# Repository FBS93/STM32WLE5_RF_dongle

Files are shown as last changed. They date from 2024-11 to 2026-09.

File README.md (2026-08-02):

# SMT32WLE5_RF_dongle

This project is developed using [Embedded Workbench](doc/ew.md).

The **SMT32WLE5_RF_dongle** is a compact RF dongle designed for wireless communication via USB. Built around the STM32WLE5C8U6 microcontroller, it enables straightforward radio communication in the sub-GHz range of 150–960 MHz. Supports LoRa and (G)FSK modulations for both transmission and reception, as well as BPSK/(G)MSK for transmission only.

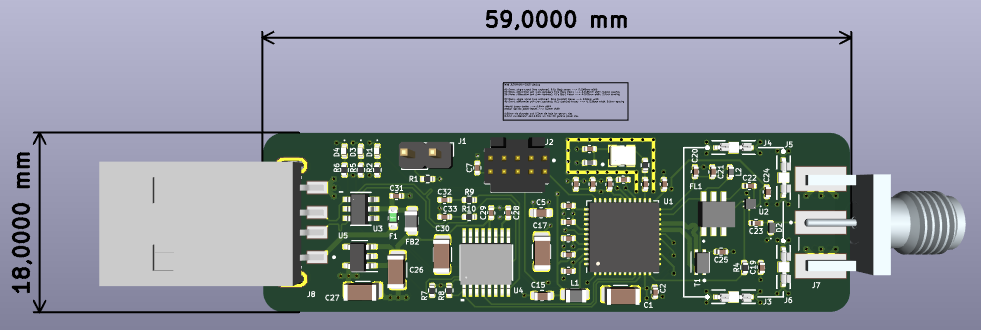
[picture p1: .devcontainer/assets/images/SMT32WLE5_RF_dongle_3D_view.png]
SMT32WLE5_RF_dongle


This repository provides both the hardware design and an example software project that includes firmware for the STM32WLE5C8U6 microcontroller, along with a Kivy-based desktop app to control the RF dongle. The project is packaged in a devcontainer for Visual Studio Code, but adaptable as needed.

Below you will find a brief guide on how to set up the development environment used.

# Setting up the development environment

## Development environment

The following setup was used during the development of this project. While the project should work with similar setups, using these versions will help minimize compatibility issues.

- **Windows Subsystem for Linux (WSL)**: version 2.3.24.0
- **Visual Studio Code**: version 1.95.2
- **Remote Development (VSode extension)**:  version 0.26.0
- **ST-LINK/V2**

Useful links:

- [Developing inside a Container](https://code.visualstudio.com/docs/devcontainers/containers)
- [Connecting USB devices to WSL](https://learn.microsoft.com/en-us/windows/wsl/connect-usb)

## Quick start

Once inside the devcontainer you will find the following folders:

- `hw/`: contains all the hardware design files of this project. You can find the full hardware design in a KiCad project format, including the schematic, PCB layout, and associated files. Additionally, the folder includes the KiCad libraries that were used for this design.

- `software/stm32wle5_rf_dongle_example/`: contains an example firmware for the STM32WLE5C8U6 microcontroller, along with a Kivy-based desktop app to control the RF dongle.

After opening the VSCode workspace defined in the `.vscode/.code-workspace` file, you should see the following icons in the VSCode status bar: VSCode status bar

- **[Preset]**: Presets for the STM32WLE5C8U6 firmware

- **🛠 C**: Predefined tasks to work with the STM32WLE5C8U6 firmware
  - 🔨 Build &rarr; Compile the firmware
  - 🐞 Debug &rarr; Debug the firmware on target
  - ⚡ Flash &rarr; Flash the firmware to the target
  - 🧹 Clean &rarr; Remove firmware build

- **🐍 Python**:  Predefined tasks to work with the Kivy desktop app
  - ▶ Run &rarr; Execute the Kivy app
  - 🐞 Debug &rarr; Debug the Kivy app
  - 🧹 Clean &rarr; Clean all \_\_pycache__

- **🧰 Toolbox**: Predefined tasks to open the tools used for the Hardware and Software design
  - ⚙️ STM32CubeMX
  - ⚡ KiCad

## Running the example software

The following screenshots show the communication between two SMT32WLE5_RF_dongle using the example software provided in this repository.

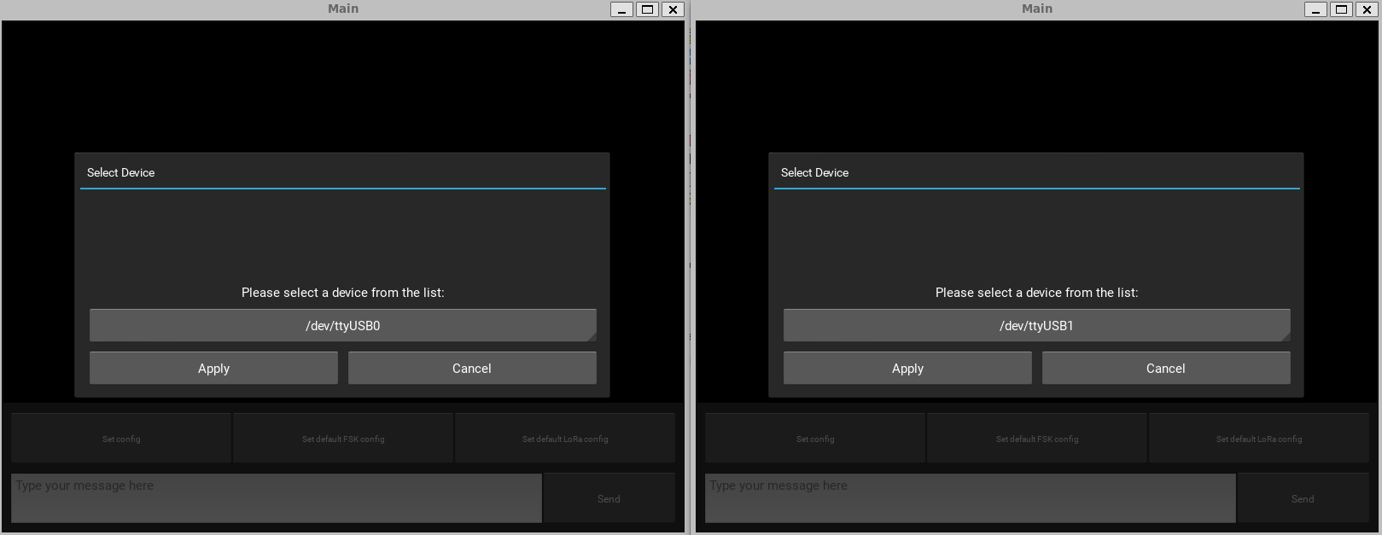
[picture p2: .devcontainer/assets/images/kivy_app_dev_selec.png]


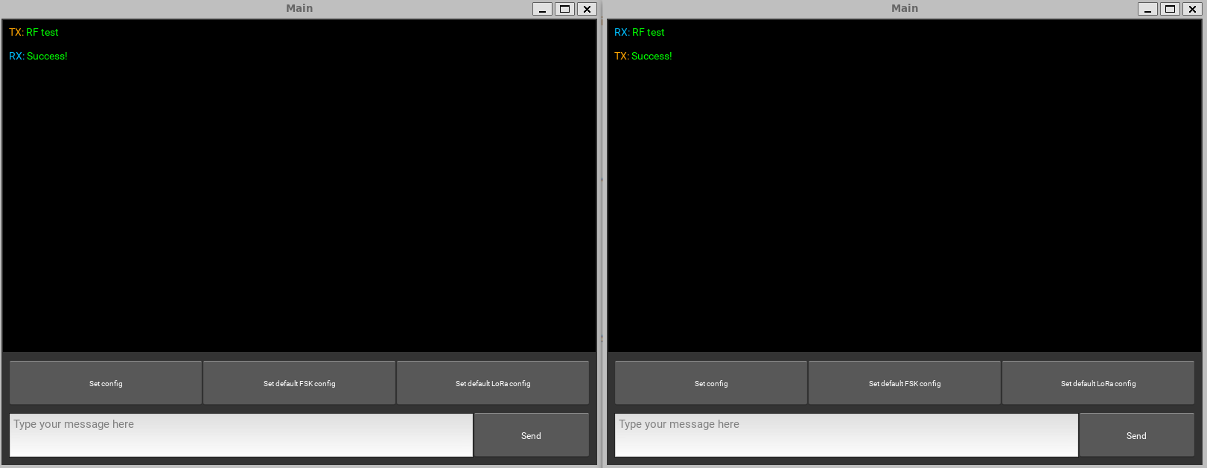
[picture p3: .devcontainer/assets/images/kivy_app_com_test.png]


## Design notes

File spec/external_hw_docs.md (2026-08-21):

# EHW_DOC_1

STMicroelectronics RM0461, reference manual for STM32WLEx advanced Arm®-based 32-bit MCUs with sub-GHz radio solution.

## References

- RM0461: STM32WLEx advanced Arm®-based 32-bit MCUs with sub-GHz radio solution - Reference manual
  - AI processing source: [rm0461-stm32wle5xx-advanced-armbased-32bit-mcus-stmicroelectronics.md](stakeholder_spec_parsed/external_doc/rm0461-stm32wle5xx-advanced-armbased-32bit-mcus-stmicroelectronics.md)
  - Original source: [rm0461-stm32wle5xx-advanced-armbased-32bit-mcus-stmicroelectronics.pdf](stakeholder_spec/external_doc/rm0461-stm32wle5xx-advanced-armbased-32bit-mcus-stmicroelectronics.pdf)

# EHW_DOC_2

STMicroelectronics DS13105, datasheet for STM32WLE5xx and STM32WLE4xx multiprotocol LPWAN 32-bit Arm® Cortex®-M4 MCUs.

## References

- DS13105: STM32WLE5xx STM32WLE4xx - Multiprotocol LPWAN 32-bit Arm® Cortex®-M4 MCUs
  - AI processing source: [stm32wle5jc.md](stakeholder_spec_parsed/external_doc/stm32wle5jc.md)
  - Original source: [stm32wle5jc.pdf](stakeholder_spec/external_doc/stm32wle5jc.pdf)

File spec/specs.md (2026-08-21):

# SPEC_1

The product shall be a laboratory RF dongle based on the selected STM32WLE5 microcontroller (MCU) named `STM32WLE5_RF_dongle`.

Milestone: M_1

Status: approved

# SPEC_2

The `STM32WLE5_RF_dongle` hardware and software shall both be developed within this project.

Milestone: M_1

Status: approved

# SPEC_3

The `STM32WLE5_RF_dongle` shall be operated from a USB-connected host and support both manual control and automated scripting.

Milestone: M_1

Status: approved

# SPEC_4

The host shall be able to configure RF operation of `STM32WLE5_RF_dongle` using all modulation and configuration capabilities provided by the selected STM32WLE5 MCU.

Milestone: M_1

Status: approved

# SPEC_5

The host shall be able to request RF transmission and reception to `STM32WLE5_RF_dongle`.

Milestone: M_1

Status: approved

# SPEC_6

The `STM32WLE5_RF_dongle` shall provide the host with the active RF operation and radio operational errors.

Milestone: M_1

Status: approved

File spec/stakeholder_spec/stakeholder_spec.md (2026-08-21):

# Stakeholder specification

## Product purpose

The product shall be a laboratory RF dongle based on the selected STM32WLE5 microcontroller (MCU) named `STM32WLE5_RF_dongle`. The `STM32WLE5_RF_dongle` hardware and software shall both be developed within this project.

## Host control and RF operation

The `STM32WLE5_RF_dongle` shall be operated from a USB-connected host and support both manual control and automated scripting.

The host shall be able to configure RF operation of `STM32WLE5_RF_dongle` using all modulation and configuration capabilities provided by the selected STM32WLE5 MCU.

The host shall be able to request RF transmission and reception to `STM32WLE5_RF_dongle`.

## Operational status and diagnostics

The `STM32WLE5_RF_dongle` shall provide the host with the active RF operation and radio operational errors.

## External documentation

- [RM0461: STM32WLEx advanced Arm®-based 32-bit MCUs with sub-GHz radio solution - Reference manual](external_doc/rm0461-stm32wle5xx-advanced-armbased-32bit-mcus-stmicroelectronics.pdf)
- [DS13105: STM32WLE5xx STM32WLE4xx - Multiprotocol LPWAN 32-bit Arm® Cortex®-M4 MCUs](external_doc/stm32wle5jc.pdf)

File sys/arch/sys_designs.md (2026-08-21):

# sys_designs

## SYS_ARCH_DESIGN_1

Name: sysd_systemModes

The system modes are defined in the [sys_modes_state_diagram.md](sys_modes_state_diagram.md) document.

Upstream traceability:
- [SYS_REQ_PRODUCT_1](../req/sys_product.md#sys_req_product_1)
- [SYS_REQ_INTERFACE_1 — command processing](../req/sys_interfaces.md#command-processing)
- [SYS_REQ_INTERFACE_1 — host requests](../req/sys_interfaces.md#host-to-target-requests)
- [SYS_REQ_INTERFACE_2](../req/sys_interfaces.md#sys_req_interface_2)
- [RX operation](../req/sys_interfaces.md#rx-operation)
- [CAD operation](../req/sys_interfaces.md#cad-operation)
- [SYS_REQ_PARAMETER_46](../req/sys_parameters.md#sys_req_parameter_46)

Status: approved

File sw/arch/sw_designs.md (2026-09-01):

# sw_designs

## SW_ARCH_DESIGN_1

Name: swd_eventDrivenModel

This architecture shall follow an event-driven model using Event Driven Framework (EDF).

Events:
- `GET_CONFIG_REQUEST`
  - Description: Represents the [GET_CONFIG_REQUEST](../../sys/req/sys_interfaces.md#get-config-request) command.
- `SET_CONFIG`
  - Description: Represents the [SET_CONFIG](../../sys/req/sys_interfaces.md#set-config-request) command.
  - Parameters:
    - `configuration_payload`: [Configuration Payload](../../sys/req/sys_interfaces.md#configuration-payload).
- `CALIBRATE`
  - Description: Represents the [CALIBRATE](../../sys/req/sys_interfaces.md#calibrate-request) command.
  - Parameters:
    - `calibration_payload`: [Calibration Payload](../../sys/req/sys_interfaces.md#calibration-payload).
- `TX_PACKET`
  - Description: Represents the [TX_PACKET](../../sys/req/sys_interfaces.md#tx-packet-request) command.
  - Parameters:
    - `tx_packet_payload`: [TX Packet Payload](../../sys/req/sys_interfaces.md#tx-packet-payload).
- `RX_START`
  - Description: Represents the [RX_START](../../sys/req/sys_interfaces.md#rx-start-request) command.
- `CAD_START`
  - Description: Represents the [CAD_START](../../sys/req/sys_interfaces.md#cad-start-request) command.
- `TX_CONTINUOUS_WAVE`
  - Description: Represents the [TX_CONTINUOUS_WAVE](../../sys/req/sys_interfaces.md#tx-continuous-wave-request) command.
- `TX_CONTINUOUS_PREAMBLE`
  - Description: Represents the [TX_CONTINUOUS_PREAMBLE](../../sys/req/sys_interfaces.md#tx-continuous-preamble-request) command.
- `STOP`
  - Description: Represents the [STOP](../../sys/req/sys_interfaces.md#stop-request) command.
- `GET_DIAGNOSTICS_REQUEST`
  - Description: Represents the [GET_DIAGNOSTICS_REQUEST](../../sys/req/sys_interfaces.md#get-diagnostics-request) command.
- `GET_CONFIG_RESPONSE`
  - Description: Represents the [GET_CONFIG_RESPONSE](../../sys/req/sys_interfaces.md#get-config-response) command.
  - Parameters:
    - `configuration_payload`: [Configuration Payload](../../sys/req/sys_interfaces.md#configuration-payload).
- `GET_DIAGNOSTICS_RESPONSE`
  - Description: Represents the [GET_DIAGNOSTICS_RESPONSE](../../sys/req/sys_interfaces.md#get-diagnostics-response) command.
  - Parameters:
    - `diagnostics_payload`: [Diagnostics Payload](../../sys/req/sys_interfaces.md#diagnostics-payload).
- `RX_PACKET`
  - Description: Represents the [RX_PACKET](../../sys/req/sys_interfaces.md#rx-packet) command.
  - Parameters:
    - `rx_packet_payload`: [RX Packet Payload](../../sys/req/sys_interfaces.md#rx-packet-payload).
- `CAD_DETECTED`
  - Description: Represents the [CAD_DETECTED](../../sys/req/sys_interfaces.md#cad-detected) command.
- `OPERATION_COMPLETE`
  - Description: Indicates that the active RF operation has completed.
- `HOST_DATA_AVAILABLE`
  - Description: Indicates that data received from the host is available for processing.

Upstream traceability:
- [SW_REQ_CLI_1](../req/sw_cli.md#sw_req_cli_1)
- [SW_REQ_CONTROLLER_1](../req/sw_controller.md#sw_req_controller_1)
- [SW_REQ_INTERFACE_1](../req/sw_interfaces.md#sw_req_interface_1)
- [SW_REQ_INTERFACE_2](../req/sw_interfaces.md#sw_req_interface_2)

Status: approved

## SW_ARCH_DESIGN_2

Name: swd_platform

The platform shall be defined as follows:

Toolchains:
- Host SiL/emulation: use the existing [linux_gcc.cmake](../../tools/cmake/toolchains/linux_gcc.cmake) toolchain.
- Target executable: use the existing [arm_gcc.cmake](../../tools/cmake/toolchains/arm_gcc.cmake) toolchain.

Build configuration:
- The following elements are CMake configure presets. Each preset selects the build configuration, optimization level and debug information level. The common warning options `-Wall -Wextra -Wconversion -Werror` apply to the listed product presets through a base configuration.
  - Host SiL/emulation:
    - `host`: CMAKE_BUILD_TYPE `Release`, optimization `-O2` and debug information `-g2`.
    - `host_debug`: CMAKE_BUILD_TYPE `Debug`, optimization `-O0` and debug information `-g3`.
    - `host_hard_debug`: CMAKE_BUILD_TYPE `Debug`, optimization `-O0`, debug information `-g3` and generation of preprocessed files for inspection `-save-temps=obj -P`.
  - Target:
    - `target_stm32wle5c8u6`: CMAKE_BUILD_TYPE `Release`, optimization `-O2` and debug information `-g2`.
    - `target_stm32wle5c8u6_debug`: CMAKE_BUILD_TYPE `Debug`, optimization `-O0` and debug information `-g3`.
    - `target_stm32wle5c8u6_hard_debug`: CMAKE_BUILD_TYPE `Debug`, optimization `-O0`, debug information `-g3` and generation of preprocessed files for inspection `-save-temps=obj -P`.

RAM layout:
| Name | Description | Start address | End address |
|---|---|---|---|
| target_sram2 | STM32WLE5C8U6 SRAM2. The C8 density provides 20 Kbytes; RM0461 maps SRAM2 from 0x2000 8000. | 0x2000 8000 | 0x2000 CFFF |

ROM layout:
| Name | Description | Start address | End address |
|---|---|---|---|
| target_program_flash | STM32WLE5C8U6 user flash. The C8 density provides 64 Kbytes and RM0461 maps user flash from 0x0800 0000. | 0x0800 0000 | 0x0800 FFFF |

NVM layout:
| Name | Description | Start address | End address |
|---|---|---|---|
| target_nvm_none | No NVM region is currently used. | N/A | N/A |

Debug configuration:
- The target shall use SWD as its debug interface.

Embedded C Framework (ECF) integration:
- The target ECF stdout shall use the ITM/TPIU/SWO interface with the following configuration:
  - TPIU asynchronous output protocol: NRZ.
  - Nominal SWO bitrate: 2 Mbit/s.
  - The target ECF stdout shall use a non-blocking 1024-byte buffer.
- Target ECF stdin is not supported.

Upstream traceability:
- [SW_REQ_PLATFORM_1](../req/sw_platform.md#sw_req_platform_1)
- [SW_REQ_PLATFORM_2](../req/sw_platform.md#sw_req_platform_2)
- [SW_REQ_PLATFORM_3](../req/sw_platform.md#sw_req_platform_3)
- [SW_REQ_PLATFORM_4](../req/sw_platform.md#sw_req_platform_4)
- [SW_REQ_PLATFORM_5](../req/sw_platform.md#sw_req_platform_5)
- [SW_REQ_PLATFORM_6](../req/sw_platform.md#sw_req_platform_6)
- [SW_REQ_PLATFORM_7](../req/sw_platform.md#sw_req_platform_7)

Status: approved

## SW_ARCH_DESIGN_3

Name: swd_hostCliScope

The [swc_hostCli](sw_components.md#sw_arch_component_1) shall be implemented as a Python 3 application for POSIX. It is defined up to software architecture only; downstream software-domain processes do not apply. The [swc_hostCli](sw_components.md#sw_arch_component_1) remains subject to system integration and qualification testing.

Upstream traceability:
- [SW_REQ_CLI_1](../req/sw_cli.md#sw_req_cli_1)

Status: approved

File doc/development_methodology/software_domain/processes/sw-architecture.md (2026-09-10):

# sw-architecture

## Purpose

Define software architecture from software requirements.

## Input work products

- Software requirements

## Output work products

- Software architecture

## Steps

1. Review the software requirements.
2. Identify the software architecture elements required to address the software requirements.
3. Define the software architecture based on the identified software architecture elements.
4. Define traceability between software architecture elements and software requirements.
5. Check the software architecture for completeness, consistency and correctness.

## Guidelines

### Software architecture work product

The software architecture work product shall follow the [Architecture definition](../../resources/architecture_definition.md).

#### Architecture model

The software architecture shall follow an event-driven model. The use of this architecture model with the [Event Driven Framework (EDF)](../../../../sw/ecf/event_driven_framework/doc/edf.md) shall be defined as a software design.

The software architecture shall be aligned with the capabilities and features of the [Event Driven Framework (EDF)](../../../../sw/ecf/event_driven_framework/doc/edf.md).

The software design defining the use of the event-driven architecture model shall contain:
- A justification of the selection of the event-driven model and the use of EDF with a fixed sentence.
- Architectural decisions specific to the use of the event-driven model, such as active-object priorities (including preemption-threshold relationships when applicable), event-pool sizing, time-event usage, and other applicable model-specific decisions.
- The definition of the complete set of available software events. Each event shall be specified with:
  - An event name in UPPER_SNAKE_CASE. The event name shall be unique, as it is used as the event identifier.
  - A description defining the event. The description shall include all necessary information to fully specify the event, written in a clear and concise manner.
  - Event parameters when applicable. Each parameter shall be specified with:
    - A parameter name in lower_snake_case. The parameter name shall be unique within the event, as it is used as the parameter identifier.
    - A description defining the parameter. The description shall include all necessary information to fully specify the parameter, written in a clear and concise manner.

The following template shall be used for the description of this software design:

```md
This architecture shall follow an event-driven model using Event Driven Framework (EDF).
<Event-driven model architectural decisions>.

Events:
- `<EVENT_NAME>`
  - Description: <Event description>.
  - Parameters:
    - `<param_name>`: <Parameter description>.
```

The `Parameters` subsection shall be included only when the event has parameters.

In this architecture model, all project-specific software components shall be defined as active objects. Each active object shall:
- Encapsulate its own state and behavior.
- Process events asynchronously without blocking or sharing resources with other software components.

Hint: If a shared resource is identified, the solution might be to isolate it in a dedicated active object and access it from other active objects through events.

Events, using the EDF publish/subscribe mechanism, shall be the only way of interaction between software components. Direct function calls between software components are not permitted.

A software component named `EDF` shall be defined and linked to the software design defining the use of the event-driven architecture model. This software component shall be used in the architecture views to represent the unique way of interaction between project-specific software components.

Each software component shall use a single architecture interface to `EDF` software component. The description of this interface shall contain:
- A list of published events.
- A list of subscribed events.

Events in both lists shall be referenced only by their `EVENT_NAME`, which is the unique identifier of the event defined in the software design defining the use of the event-driven architecture model.

The following template shall be used for the description of each interface used for a given software component:

```md
Published events:
- <EVENT_NAME>
- <EVENT_NAME>

Subscribed events:
- <EVENT_NAME>
- <EVENT_NAME>
```

#### Platform

The software architecture shall define the platform as a software design.

The platform software design shall define the platform-specific architectural decisions and default configurations.

All platform characteristics required to define the software architecture shall be provided by upstream elements. If relevant platform characteristics are not defined by upstream elements and no valid default option is available, the software architecture process shall not be completed until the missing information is defined upstream.

The platform software design shall contain:
- Toolchains:
  - If the target toolchain is not explicitly defined by upstream elements and the MCU architecture is ARM, the default option for the target shall be the [arm_gcc.cmake](../../../../tools/cmake/toolchains/arm_gcc.cmake) toolchain.
  - If the host toolchain is not explicitly defined by upstream elements, the default option for the host shall be the [linux.cmake](../../../../tools/cmake/toolchains/linux_gcc.cmake) toolchain.
- Build configuration:
  - If upstream elements do not specify the build configuration and the MCU architecture is ARM, the default build presets shall be:
    - `host`: Host execution (SiL) in release configuration.
    - `host_debug`: Host execution (SiL) in debug configuration.
    - `host_hard_debug`: Host execution (SiL) in debug configuration with preprocessed source code available for inspection.
    - `target_<platform>`: Target embedded execution in release configuration.
    - `target_<platform>_debug`: Target embedded execution in debug configuration.
    - `target_<platform>_hard_debug`: Target embedded execution in debug configuration with preprocessed source code available for inspection.
  - If build flags for the selected toolchain are not explicitly defined or are not self-evident, they shall be defined here, including the presets to which they apply.
- ISR integration strategy:
  - Architectural decisions for ISR integration, including interrupt sources, ownership, priority ordering and other applicable ISR-specific decisions.
- Memory layout:
  - A memory layout divided into RAM layout, ROM layout (e.g., program flash, ...) and NVM layout (e.g., persistent parameters, persistent data, ...). Each memory layout shall be represented as a Markdown table. Each row of this table represents a memory region of the memory layout and may describe any level of granularity, ranging from a memory block to individual parameters. Each memory region shall be specified with:
    - A memory region name in lower_snake_case. The memory region name shall be unique across all memory layouts, as it is used as the memory region identifier.
    - A description defining the memory region. The description shall include all necessary information to fully specify the memory region, written in a clear and concise manner.
    - The start address of the memory region.
    - The end address of the memory region.
- Debug configuration:
  - Definition of the debug interfaces used (e.g., SWD, JTAG, etc.).
- [Embedded C Framework (ECF)](../../../../sw/ecf/doc/ecf.md) integration:
  - Integration strategy for [Embedded Base Framework (EBF)](../../../../sw/ecf/embedded_base_framework/doc/ebf.md) stdin/stdout integration. Upstream elements shall define the interface used for this integration. If no further detail is specified by upstream elements, the default shall be:
    - Stdin listener shall be executed in the reception ISR context.
    - Stdout shall use buffered transmission handled by ISR.
    - Stdout buffer size shall be configurable and defined according to the memory constraints of the target platform.

The following template shall be used for the description of this software design:

```md
The platform shall be defined as follows:

Toolchains:
- <Design decisions related to the selected toolchains>.

Build configuration:
- <Design decisions related to the selected build configuration>.

ISR integration strategy:
- <Design decisions related to the ISR integration strategy>.

RAM layout:
| Name | Description | Start address | End address |
|---|---|---|---|
| <memory_region_name> | <Description>. | <Start address in hexadecimal format> | <End address in hexadecimal format> |

ROM layout:
| Name | Description | Start address | End address |
|---|---|---|---|
| <memory_region_name> | <Description>. | <Start address in hexadecimal format> | <End address in hexadecimal format> |

NVM layout:
| Name | Description | Start address | End address |
|---|---|---|---|
| <memory_region_name> | <Description>. | <Start address in hexadecimal format> | <End address in hexadecimal format> |

Debug configuration:
- <Design decisions related to the selected debug configuration>.

Embedded C Framework (ECF) integration:
- <Design decisions related to the Embedded C Framework (ECF) integration strategy>.
```

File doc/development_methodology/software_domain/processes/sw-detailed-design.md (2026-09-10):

# sw-detailed-design

## Purpose

Define software detailed design from software requirements and software architecture.

## Input work products

- Software requirements
- Software architecture

## Output work products

- Software detailed design

## Steps

1. Review the software requirements and software architecture.
2. Identify the software units required to address the software requirements and software architecture.
3. Define the detailed design of each software unit.
4. Define traceability between software detailed design and software architecture.
5. Check the software detailed design for completeness, consistency and correctness.

## Guidelines

### Software detailed design work product

Software detailed designs shall be derived from software architecture and software requirements.

Software requirements shall be used only as complementary input when the software architecture does not fully define the required behavior.

Software detailed designs shall not define direct traceability to software requirements.

All software architecture elements shall be traced to one or more software units. Each software architecture element may be refined into one or more software units (1:1 or 1:N) depending on the software detailed design needs.

In cases where a software component is refined into multiple software units (1:N), it is recommended to group the corresponding software units under a common folder named the same as the software component.

Each software unit shall use a descriptive `lower_snake_case` name. This name shall be the common base name for its folder, Markdown document, headers, source files and implemented library. When a software component is refined 1:1 as a software unit, the software unit name shall be derived by removing the architectural `swc_` prefix and converting the remaining name to `lower_snake_case`.

Software units shall be reused from existing libraries when available. Before creating a new software unit or implementing project-specific functionality within a software unit, it shall be verified whether the required functionality can be provided by [Embedded C Framework (ECF)](../../../../sw/ecf/doc/ecf.md). If a specific implementation within a software unit is still required, it shall be assessed whether it can be fully or partially designed as reusable software for other projects and therefore implemented in [Embedded C Framework (ECF)](../../../../sw/ecf/doc/ecf.md). Project-specific software implementation shall be minimized.

Each project-specific software unit shall have its own software detailed design and shall consist of:
- A Markdown document named `<sw_unit_name>.md` following the template defined in [embedded_c_guidelines.md](../resources/embedded_c_coding_guidelines.md#librarymodule-documentation) with the following additional information:
  - A unique identifier defined as a top Markdown heading (all other headings defined in the [embedded_c_guidelines.md](../resources/embedded_c_coding_guidelines.md#librarymodule-documentation) template shall be shifted one level below this top heading), following the pattern: `SW_DETAILED_DESIGN_<X>`
    - `<X>` is a monotonically increasing number that shall never be reused.
  - The `<Library/module name> overview` chapter placeholder shall be replaced with the software unit name used in the document name using the following pattern `<Software unit name> overview`. The chapter shall contain the following information:
    - A description defining the software unit. The description shall include all necessary information to fully specify the software unit, written in a clear and concise manner.
      - The description of software units with executable behavior shall document that all fault handling not explicitly defined by upstream elements shall be handled using a Design by Contract (DbC) approach with the [Embedded Assert Framework (EAF)](../../../../sw/ecf/embedded_assert_framework/doc/eaf.md).
    - Upstream traceability to one or more software architecture elements. Shall be defined as a list of Markdown links referencing the corresponding software architecture elements.
    - A list of hardware resources used directly by the software unit, including their usage.
    - A list of external library dependencies, including their usage.
  - A status indicating the approval state of the software unit detailed design. Shall use exactly one of these values: `not approved`, `approved`.
  - The remaining chapters of the [library/module documentation](../resources/embedded_c_coding_guidelines.md#librarymodule-documentation) template shall follow this project-specific content in their original order.
- A behavioral model, when required. Each software unit that requires behavioral modeling shall have exactly one representation, selected as follows:
  - Mermaid shall be used for manual design, review and implementation. Mermaid models shall be `.md` files containing `mermaid` blocks and may define HSMs using `stateDiagram-v2` and activities using `flowchart`, as needed.
  - [MBSE](https://github.com/FBS93/mbse) shall be used when model execution, automated semantic validation or generation is required.
- Header files of the software unit, if any. When a public interface is required, `<sw_unit_name>.h` shall define it. Additional header files, if any, shall be named following the pattern `<sw_unit_name>_<header_specific_suffix>.h` and are intended to support the internal structure and detailed design of the software unit. All header files of the software unit shall follow the rules defined in [embedded_c_guidelines.md](../resources/embedded_c_coding_guidelines.md).

The following additions to the Markdown document template shall be applied to project-specific software units, in addition to the template defined in [embedded_c_guidelines.md](../resources/embedded_c_coding_guidelines.md#librarymodule-documentation):

```md
# SW_DETAILED_DESIGN_<X>

## <Software unit name> overview

<Description>.

Upstream traceability:
- [<UPSTREAM_ELEMENT_UNIQUE_ID>](#...)

Hardware resources:
- <Hardware resource>: <Short description of its usage>

External dependencies:
- <External library name>: <Short description of its usage>

Status: <status>

<Remaining chapters from the [library/module documentation](../resources/embedded_c_coding_guidelines.md#librarymodule-documentation) template, in their original order.>
```

For software units with executable behavior, the following text shall be inserted immediately after `<Description>.`:

```md
All undefined fault handling cases shall be handled using a Design by Contract (DbC) approach with the Embedded Assert Framework (EAF) as follows:
  - An assert shall be triggered for any unexpected software condition (e.g., invalid states, unexpected values, unexpected execution paths, invalid function parameters, ...).
  - Upon assert trigger, the software shall enter an infinite loop with a critical section active to prevent further execution.
```

For software units with executable behavior, the following dependency shall also be included under `External dependencies`:

```md
- Embedded Assert Framework (EAF): Provides assertions to enforce Design by Contract (DbC) in all undefined fault handling cases.
```

#### Active object detailed design

If the software architecture specifies an event-driven model as a software design, all software components defined in the architecture as active objects shall be refined 1:1 into software units. A dedicated software unit named `events` shall be defined as header-only, containing all events defined in this software design, so that it is available to all active objects and can be used during implementation. This does not preclude the definition of other types of software units derived from other software architecture elements.

The software detailed design of software units implemented as active objects shall not duplicate information already defined in the corresponding software component. Instead, it shall extend it where needed and define upstream traceability to the corresponding software component.

The software detailed design of software units implemented as active objects shall be aligned with the capabilities and features of the [Event Driven Framework (EDF)](../../../../sw/ecf/event_driven_framework/doc/edf.md). As this framework will be used for their implementation, it shall be listed as a dependency in the software detailed design.

The software detailed design of a software unit implemented as an active object shall contain the following information in addition to the generic software unit detailed design:
- The definition of its Hierarchical State Machine (HSM) and activities in its behavioral model.
  - The HSM definition shall be kept as simple as possible. It shall only extract event parameters and apply minimal logic to trigger specific functions (activities) based on the received event. Functional logic shall not be implemented directly in the HSM.
  - All activities and states defined in the HSM shall correspond to function names to be implemented. These function names shall follow the naming conventions defined in [embedded_c_guidelines.md](../resources/embedded_c_coding_guidelines.md#naming-conventions).
  - Activities defined in the HSM shall be declared in a header file named `<sw_unit_name>_activities.h` to allow unit testing when required.

#### Platform package detailed design

If the software architecture specifies the platform as a software design, a software unit of type platform package shall be defined. Existing platform packages in [Embedded C Framework (ECF)](../../../../sw/ecf/doc/ecf.md) shall be reviewed first and reused when available. A new platform package may be project-specific at `sw/src/<platform_name>_platform/`; when it shows actual reuse potential, it may be promoted to `sw/ecf/platform/<platform_name>/`. Only one canonical active implementation shall be used, so promotion shall replace the project-specific implementation rather than copy it.

A project-specific platform package shall use the project-specific software unit template defined above. A reusable ECF platform package shall use only the [library/module documentation](../resources/embedded_c_coding_guidelines.md#librarymodule-documentation) template and shall not contain project-specific traceability.

A software unit named `stdio` shall be defined within the platform package to implement [Embedded Base Framework (EBF)](../../../../sw/ecf/embedded_base_framework/doc/ebf.md) stdin/stdout integration as specified in the platform software design. Whether within a project-specific or ECF platform package, its documentation shall use only the template defined in [embedded_c_guidelines.md](../resources/embedded_c_coding_guidelines.md#librarymodule-documentation).

For a reused or promoted ECF platform package, the project shall retain a software detailed design Markdown document based on the project-specific software unit template defined above. Only its `<Description>` placeholder shall be specialized, using exactly the following text:

```md
This software unit is implemented by the [<platform_name> ECF platform package](<link_to_ECF_platform_package_markdown_document>).
```

A platform package shall be identified by `<platform_name>`, which shall be a descriptive identifier reflecting its scope (e.g., MCU family, board, execution environment, ...). In ECF platform packages, `ECF_TARGET_PLATFORM` name shall equal the ECF platform package folder name `<platform_name>`.

The [STM32F103C8Tx platform package](../../../../sw/ecf/platform/stm32f103c8tx/doc/stm32f103c8tx_platform_package.md) shall be used as the reference example for platform packages.

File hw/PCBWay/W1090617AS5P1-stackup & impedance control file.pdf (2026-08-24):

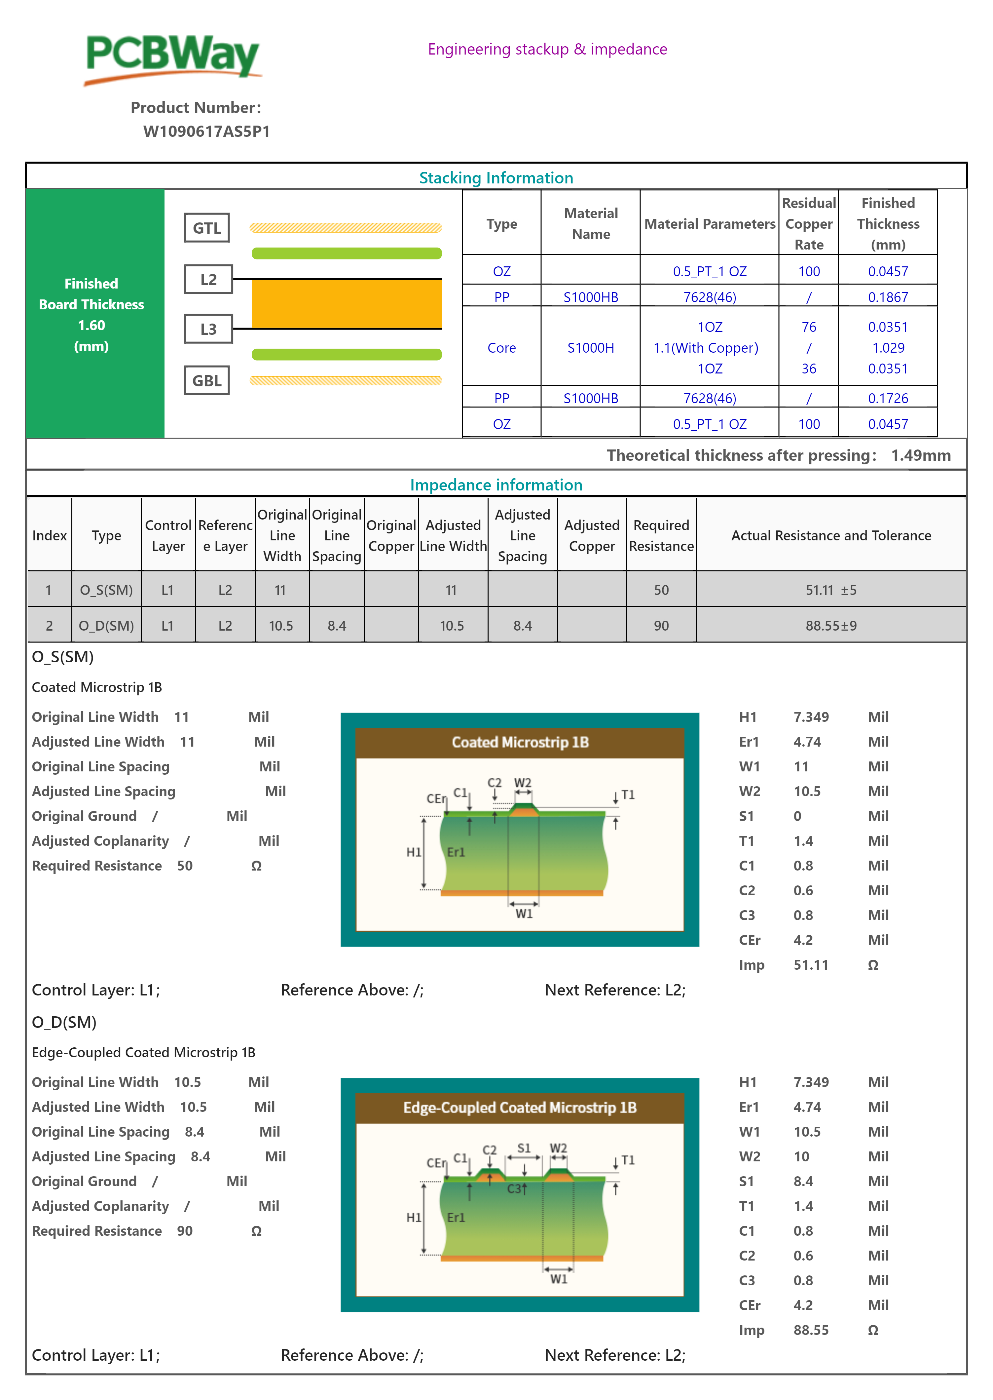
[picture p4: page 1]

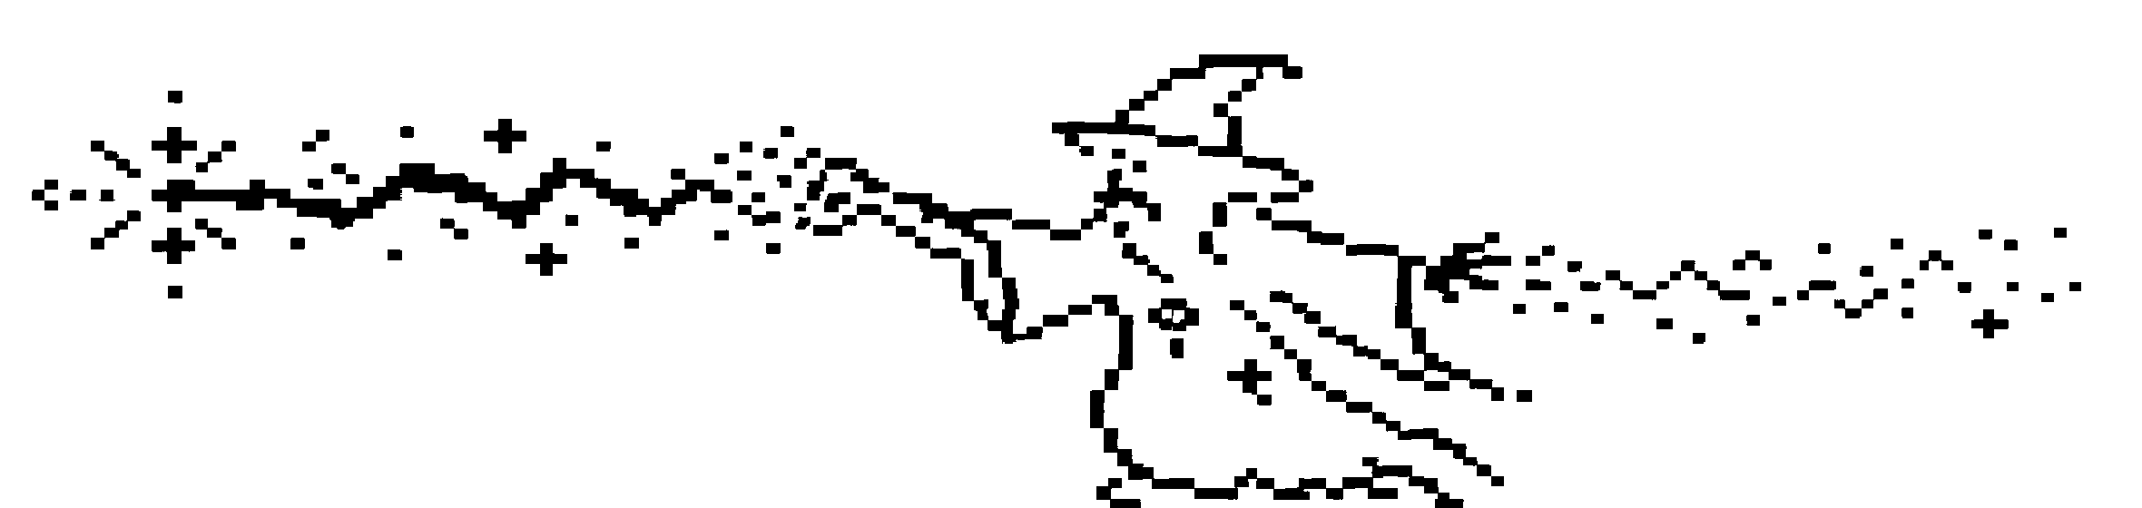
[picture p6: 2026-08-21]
hw/KiCad/assets/RF_Wizard.png

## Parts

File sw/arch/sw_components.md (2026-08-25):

# sw_components

## SW_ARCH_COMPONENT_1

Name: swc_hostCli

Host-side software component. It accepts the user command line and maps the CLI behavior to the target protocol requests and responses.

The component uses [`swi_hostUsbControl`](sw_interfaces.md#sw_arch_interface_1), as the logical host-control boundary to the target deployment.

Upstream traceability:
- [SW_REQ_CLI_1](../req/sw_cli.md#sw_req_cli_1)

References:
- [SW_ARCH_INTERFACE_1](sw_interfaces.md#sw_arch_interface_1)

Status: approved

## SW_ARCH_COMPONENT_2

Name: swc_hostCommandManager

Target-side active object responsible for the host-control boundary. It owns and realizes [`swi_hostUsbControl`](sw_interfaces.md#sw_arch_interface_1) and uses [`swi_hostCommandManagerEdf`](sw_interfaces.md#sw_arch_interface_4) as its single EDF architecture interface: it publishes accepted host-control requests and subscribes to target result events, exposing back those results through [`swi_hostUsbControl`](sw_interfaces.md#sw_arch_interface_1).

Upstream traceability:
- [SW_REQ_CONTROLLER_1](../req/sw_controller.md#sw_req_controller_1)
- [SW_REQ_INTERFACE_1](../req/sw_interfaces.md#sw_req_interface_1)
- [SW_REQ_PLATFORM_4](../req/sw_platform.md#sw_req_platform_4)

References:
- [SW_ARCH_INTERFACE_1](sw_interfaces.md#sw_arch_interface_1)
- [SW_ARCH_INTERFACE_4](sw_interfaces.md#sw_arch_interface_4)
- [SW_ARCH_COMPONENT_5](#sw_arch_component_5)
- [SW_ARCH_DESIGN_1](sw_designs.md#sw_arch_design_1)
- [SW_ARCH_DESIGN_2](sw_designs.md#sw_arch_design_2)

Status: approved

## SW_ARCH_COMPONENT_3

Name: swc_rfManager

Target-side active object responsible for RF operations. It owns and realizes [`swi_rfInputOutput`](sw_interfaces.md#sw_arch_interface_2) and uses [`swi_rfManagerEdf`](sw_interfaces.md#sw_arch_interface_5) as its single EDF architecture interface: it subscribes to operation and configuration RF events, applies the RF semantic parameters from [`SW_ARCH_PARAMETER_1`](sw_parameters.md#sw_arch_parameter_1), and publishes RF result events.

Upstream traceability:
- [SW_REQ_CONTROLLER_1](../req/sw_controller.md#sw_req_controller_1)
- [SW_REQ_INTERFACE_2](../req/sw_interfaces.md#sw_req_interface_2)
- [SW_REQ_PLATFORM_6](../req/sw_platform.md#sw_req_platform_6)
- [SW_REQ_PLATFORM_7](../req/sw_platform.md#sw_req_platform_7)

References:
- [SW_ARCH_INTERFACE_2](sw_interfaces.md#sw_arch_interface_2)
- [SW_ARCH_INTERFACE_5](sw_interfaces.md#sw_arch_interface_5)
- [SW_ARCH_PARAMETER_1](sw_parameters.md#sw_arch_parameter_1)
- [SW_ARCH_COMPONENT_5](#sw_arch_component_5)
- [SW_ARCH_DESIGN_1](sw_designs.md#sw_arch_design_1)
- [SW_ARCH_DESIGN_2](sw_designs.md#sw_arch_design_2)

Status: approved

## SW_ARCH_COMPONENT_5

Name: swc_edf

Target-side reusable [Event Driven Framework (EDF)](../ecf/event_driven_framework/doc/edf.md) component. It provides the event-driven publish/subscribe mechanism used by the target active objects.

Upstream traceability:
- [SW_REQ_CONTROLLER_1](../req/sw_controller.md#sw_req_controller_1)

References:
- [SW_ARCH_DESIGN_1](sw_designs.md#sw_arch_design_1)
- [SW_ARCH_INTERFACE_4](sw_interfaces.md#sw_arch_interface_4)
- [SW_ARCH_INTERFACE_5](sw_interfaces.md#sw_arch_interface_5)

Status: approved

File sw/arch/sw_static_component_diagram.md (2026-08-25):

# sw_static_component_diagram

## Description

Static software-architecture view of the host and target deployments.

## Diagram

```mermaid
flowchart LR
    USER[User]
    RFENV((RF environment))

    subgraph HOST[POSIX host deployment]
        SW_ARCH_COMPONENT_1[swc_hostCli]
    end

    subgraph TARGET[STM32WLE5 target deployment]
        SW_ARCH_COMPONENT_2[swc_hostCommandManager]
        SW_ARCH_COMPONENT_3[swc_rfManager]
        SW_ARCH_COMPONENT_5[swc_edf]

        SW_ARCH_INTERFACE_4{{swi_hostCommandManagerEdf}}
        SW_ARCH_INTERFACE_5{{swi_rfManagerEdf}}

        SW_ARCH_COMPONENT_2 <--> SW_ARCH_INTERFACE_4 <--> SW_ARCH_COMPONENT_5
        SW_ARCH_COMPONENT_3 <--> SW_ARCH_INTERFACE_5 <--> SW_ARCH_COMPONENT_5
    end

    SW_ARCH_INTERFACE_1{{swi_hostUsbControl}}
    SW_ARCH_INTERFACE_2{{swi_rfInputOutput}}

    USER --> SW_ARCH_COMPONENT_1
    SW_ARCH_COMPONENT_1 <--> SW_ARCH_INTERFACE_1 <--> SW_ARCH_COMPONENT_2
    SW_ARCH_COMPONENT_3 <--> SW_ARCH_INTERFACE_2 <--> RFENV
```

Status: approved

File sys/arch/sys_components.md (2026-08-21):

# sys_components

## SYS_ARCH_COMPONENT_1

Name: sysc_controller

`Controller` is the indivisible system abstraction of the MCU hardware together with the software executing on it. It owns the product-side host-control endpoint, applies the RF configuration and semantic parameter set, executes the requested RF operations, emits the defined responses, and exposes the host-visible operation state and radio errors. MCU implementation details and any RF-front-end partitioning are intentionally below this system-architecture level.

Upstream traceability:
- [SYS_REQ_PRODUCT_1](../req/sys_product.md#sys_req_product_1)
- [SYS_REQ_INTERFACE_1](../req/sys_interfaces.md#sys_req_interface_1)
- [SYS_REQ_INTERFACE_2](../req/sys_interfaces.md#sys_req_interface_2)

References:
- [SYS_ARCH_INTERFACE_1](sys_interfaces.md#sys_arch_interface_1)
- [SYS_ARCH_INTERFACE_2](sys_interfaces.md#sys_arch_interface_2)
- [SYS_ARCH_DESIGN_1](sys_designs.md#sys_arch_design_1)
- [SYS_ARCH_PARAMETER_1](sys_parameters.md#sys_arch_parameter_1)
- [SYS_ARCH_PARAMETER_2](sys_parameters.md#sys_arch_parameter_2)
- [SYS_ARCH_PARAMETER_3](sys_parameters.md#sys_arch_parameter_3)
- [SYS_ARCH_PARAMETER_4](sys_parameters.md#sys_arch_parameter_4)
- [SYS_ARCH_PARAMETER_5](sys_parameters.md#sys_arch_parameter_5)
- [SYS_ARCH_PARAMETER_6](sys_parameters.md#sys_arch_parameter_6)
- [SYS_ARCH_PARAMETER_7](sys_parameters.md#sys_arch_parameter_7)
- [SYS_ARCH_PARAMETER_8](sys_parameters.md#sys_arch_parameter_8)
- [SYS_ARCH_PARAMETER_9](sys_parameters.md#sys_arch_parameter_9)
- [SYS_ARCH_PARAMETER_10](sys_parameters.md#sys_arch_parameter_10)
- [SYS_ARCH_PARAMETER_11](sys_parameters.md#sys_arch_parameter_11)
- [SYS_ARCH_PARAMETER_12](sys_parameters.md#sys_arch_parameter_12)
- [SYS_ARCH_PARAMETER_13](sys_parameters.md#sys_arch_parameter_13)
- [SYS_ARCH_PARAMETER_14](sys_parameters.md#sys_arch_parameter_14)
- [SYS_ARCH_PARAMETER_15](sys_parameters.md#sys_arch_parameter_15)
- [SYS_ARCH_PARAMETER_16](sys_parameters.md#sys_arch_parameter_16)
- [SYS_ARCH_PARAMETER_17](sys_parameters.md#sys_arch_parameter_17)
- [SYS_ARCH_PARAMETER_18](sys_parameters.md#sys_arch_parameter_18)
- [SYS_ARCH_PARAMETER_19](sys_parameters.md#sys_arch_parameter_19)
- [SYS_ARCH_PARAMETER_20](sys_parameters.md#sys_arch_parameter_20)
- [SYS_ARCH_PARAMETER_21](sys_parameters.md#sys_arch_parameter_21)
- [SYS_ARCH_PARAMETER_22](sys_parameters.md#sys_arch_parameter_22)
- [SYS_ARCH_PARAMETER_23](sys_parameters.md#sys_arch_parameter_23)
- [SYS_ARCH_PARAMETER_24](sys_parameters.md#sys_arch_parameter_24)
- [SYS_ARCH_PARAMETER_25](sys_parameters.md#sys_arch_parameter_25)
- [SYS_ARCH_PARAMETER_26](sys_parameters.md#sys_arch_parameter_26)
- [SYS_ARCH_PARAMETER_27](sys_parameters.md#sys_arch_parameter_27)
- [SYS_ARCH_PARAMETER_28](sys_parameters.md#sys_arch_parameter_28)
- [SYS_ARCH_PARAMETER_29](sys_parameters.md#sys_arch_parameter_29)
- [SYS_ARCH_PARAMETER_30](sys_parameters.md#sys_arch_parameter_30)
- [SYS_ARCH_PARAMETER_31](sys_parameters.md#sys_arch_parameter_31)
- [SYS_ARCH_PARAMETER_32](sys_parameters.md#sys_arch_parameter_32)
- [SYS_ARCH_PARAMETER_33](sys_parameters.md#sys_arch_parameter_33)
- [SYS_ARCH_PARAMETER_34](sys_parameters.md#sys_arch_parameter_34)
- [SYS_ARCH_PARAMETER_35](sys_parameters.md#sys_arch_parameter_35)
- [SYS_ARCH_PARAMETER_36](sys_parameters.md#sys_arch_parameter_36)
- [SYS_ARCH_PARAMETER_37](sys_parameters.md#sys_arch_parameter_37)
- [SYS_ARCH_PARAMETER_38](sys_parameters.md#sys_arch_parameter_38)
- [SYS_ARCH_PARAMETER_39](sys_parameters.md#sys_arch_parameter_39)
- [SYS_ARCH_PARAMETER_40](sys_parameters.md#sys_arch_parameter_40)
- [SYS_ARCH_PARAMETER_41](sys_parameters.md#sys_arch_parameter_41)
- [SYS_ARCH_PARAMETER_42](sys_parameters.md#sys_arch_parameter_42)
- [SYS_ARCH_PARAMETER_43](sys_parameters.md#sys_arch_parameter_43)
- [SYS_ARCH_PARAMETER_44](sys_parameters.md#sys_arch_parameter_44)
- [SYS_ARCH_PARAMETER_45](sys_parameters.md#sys_arch_parameter_45)
- [SYS_ARCH_PARAMETER_46](sys_parameters.md#sys_arch_parameter_46)
- [SYS_ARCH_PARAMETER_47](sys_parameters.md#sys_arch_parameter_47)

Status: approved

## SYS_ARCH_COMPONENT_2

Name: sysc_hostCli

Software component executing on the host that provides the CLI and uses `sysi_usbExternal` to communicate with `sysc_controller`.

Upstream traceability:
- [SYS_REQ_CLI_1](../req/sys_cli.md#sys_req_cli_1)
- [SYS_REQ_CLI_2](../req/sys_cli.md#sys_req_cli_2)
- [SYS_REQ_CLI_3](../req/sys_cli.md#sys_req_cli_3)
- [SYS_REQ_CLI_4](../req/sys_cli.md#sys_req_cli_4)
- [SYS_REQ_CLI_5](../req/sys_cli.md#sys_req_cli_5)
- [SYS_REQ_CLI_6](../req/sys_cli.md#sys_req_cli_6)
- [SYS_REQ_CLI_7](../req/sys_cli.md#sys_req_cli_7)

References:
- [SYS_ARCH_INTERFACE_1](sys_interfaces.md#sys_arch_interface_1)

Status: approved

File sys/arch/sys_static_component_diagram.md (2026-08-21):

# sys_static_component_diagram

## Description

Static system-architecture view.

## Diagram

```mermaid
flowchart LR
    USER[User]
    RFENV((RF environment))

    SYS_ARCH_INTERFACE_1{{sysi_usbExternal}}
    SYS_ARCH_INTERFACE_2{{sysi_rfExternal}}

    SYS_ARCH_COMPONENT_2[sysc_hostCli]
    SYS_ARCH_COMPONENT_1[sysc_controller]

    USER --> SYS_ARCH_COMPONENT_2
    SYS_ARCH_COMPONENT_2 <--> SYS_ARCH_INTERFACE_1
    SYS_ARCH_INTERFACE_1 <--> SYS_ARCH_COMPONENT_1
    SYS_ARCH_COMPONENT_1 <--> SYS_ARCH_INTERFACE_2
    SYS_ARCH_INTERFACE_2 <--> RFENV
```

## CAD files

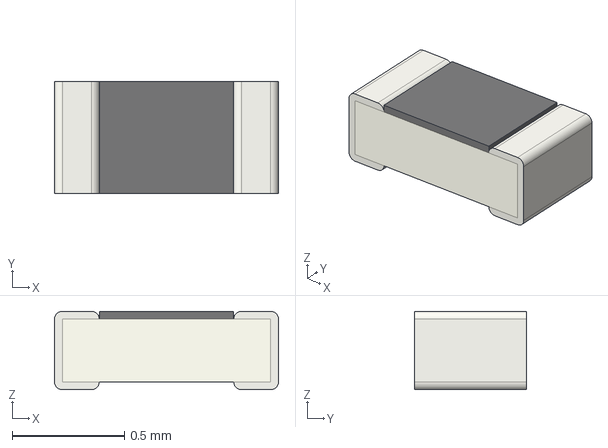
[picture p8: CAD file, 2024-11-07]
hw/FBS_kicad_lib/3d_models/0_resistor_SMD/R_0402_1005Metric.step
1.00 x 0.5 x 0.35 mm

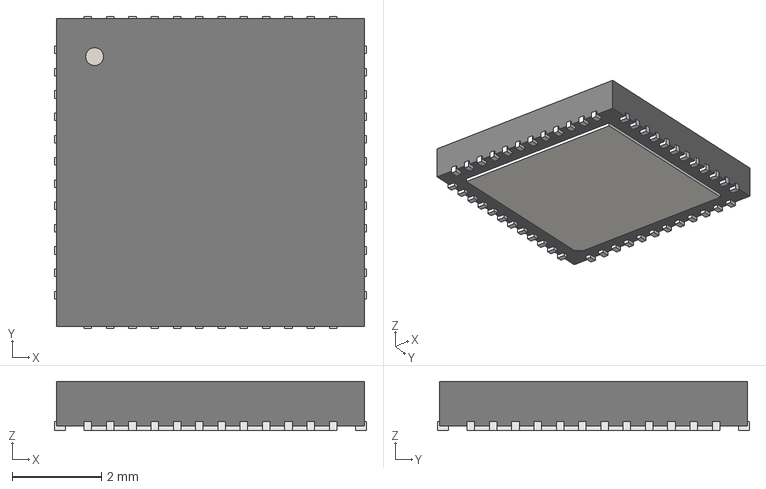
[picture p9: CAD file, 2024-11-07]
hw/FBS_kicad_lib/3d_models/100_QFN_package/QFN-48-1EP_7x7mm_P0.5mm_EP5.6x5.6mm.step
7.00 x 7.00 x 1.10 mm

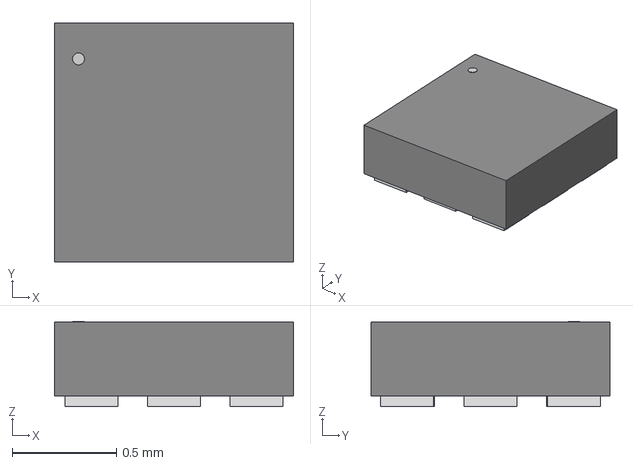
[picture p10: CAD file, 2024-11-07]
hw/FBS_kicad_lib/3d_models/101_TSNP_package/TSNP-8-1_INF.step
1.14 x 1.14 x 0.409 mm

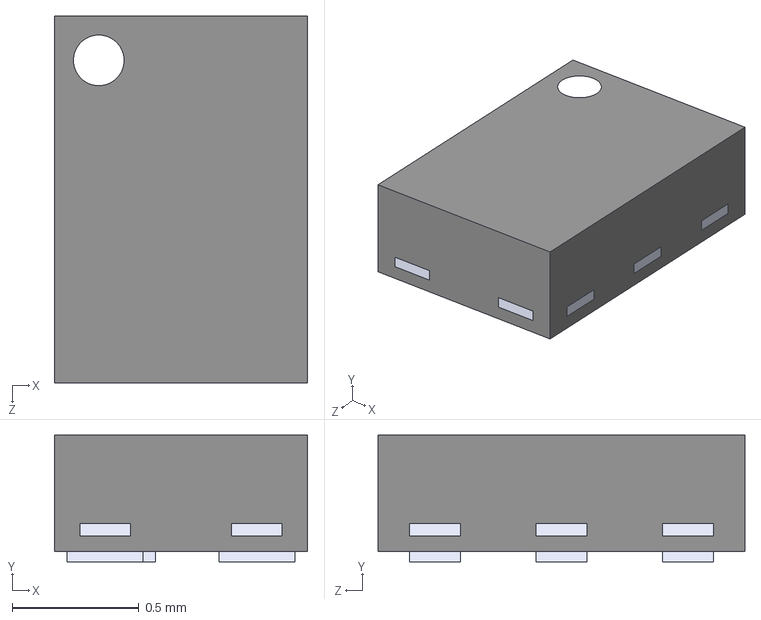
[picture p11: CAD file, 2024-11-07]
hw/FBS_kicad_lib/3d_models/102_SON_package/XSON6.step
1 x 0.5 x 1.45 mm

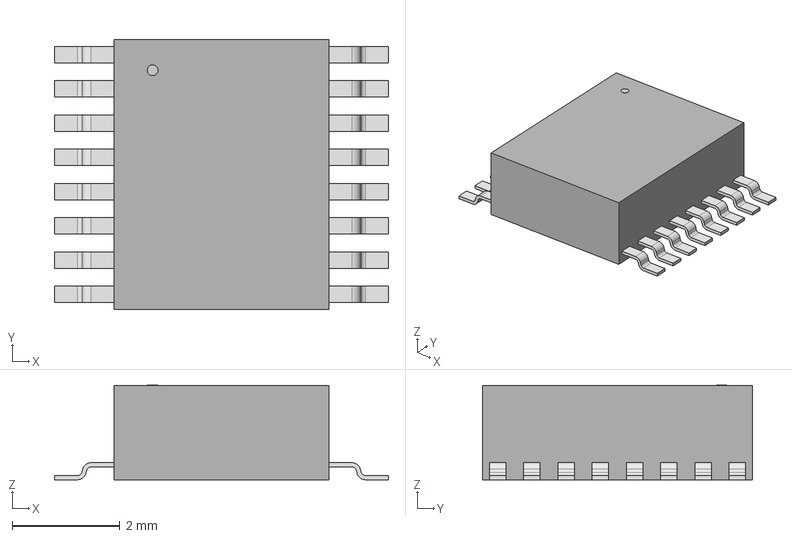
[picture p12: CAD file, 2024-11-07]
hw/FBS_kicad_lib/3d_models/103_SSOP_package/SSOP-16_FT230XS-R.step
6.20 x 5.00 x 1.75 mm

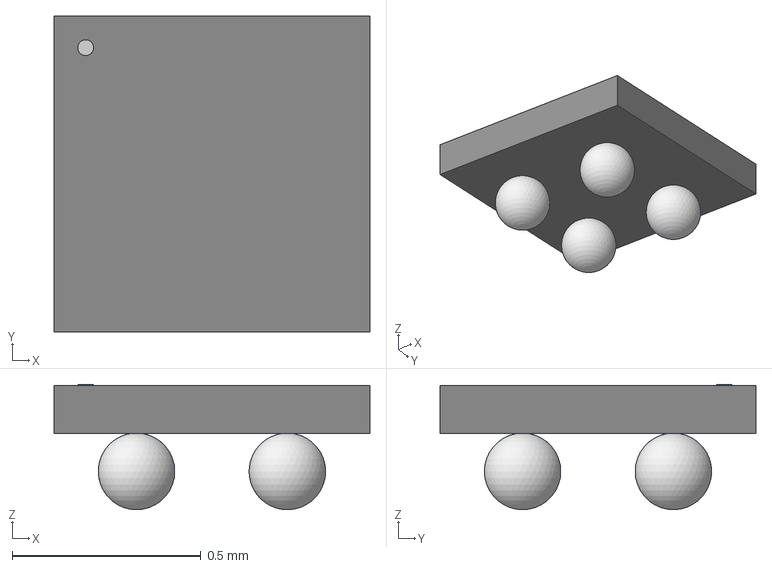
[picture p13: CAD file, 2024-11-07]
hw/FBS_kicad_lib/3d_models/104_UCSP_package/UCSP30L1_BUXXSA5WGWZ.step
0.838 x 0.838 x 0.333 mm

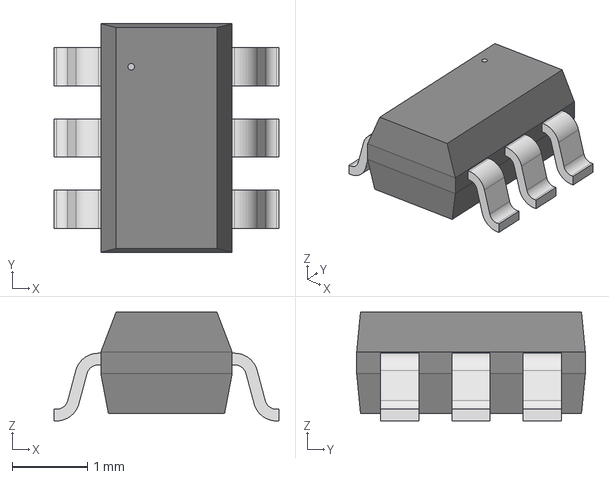
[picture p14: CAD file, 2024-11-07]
hw/FBS_kicad_lib/3d_models/105_SOT_package/SOT-23-6.step
3.00 x 3.05 x 1.45 mm

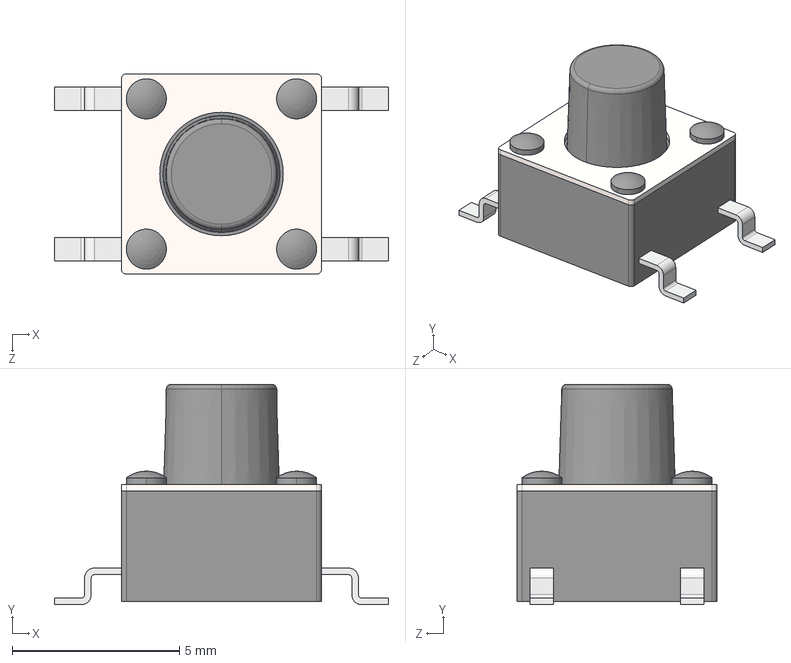
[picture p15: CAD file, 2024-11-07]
hw/FBS_kicad_lib/3d_models/10_button/TS04-66-65-BK-260-SMT.step
10.0 x 6.60 x 6.00 mm

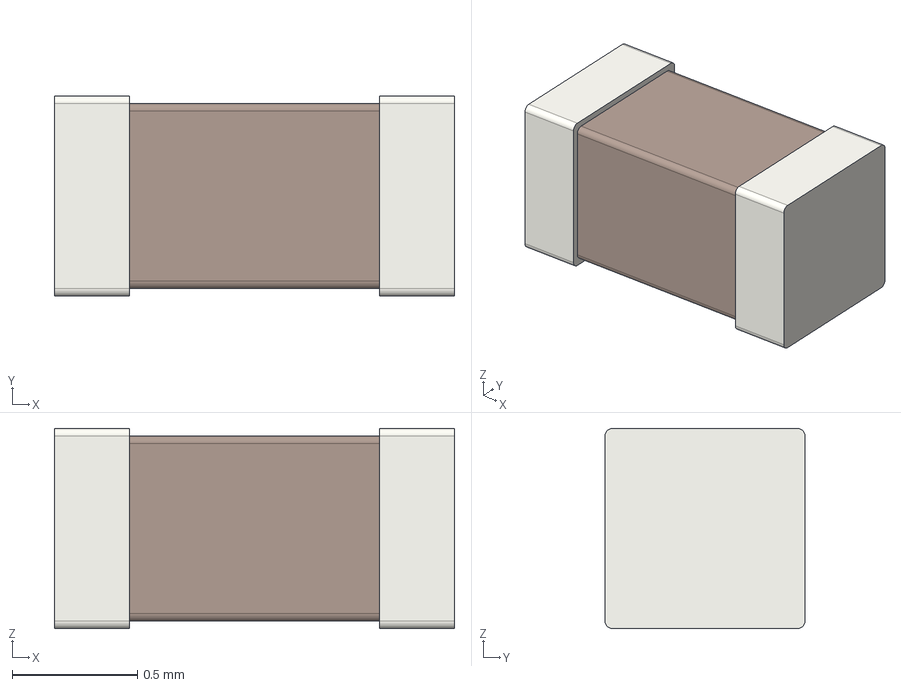
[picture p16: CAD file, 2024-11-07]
hw/FBS_kicad_lib/3d_models/1_capacitor_SMD/C_0603_1608Metric.step
1.60 x 0.8 x 0.8 mm

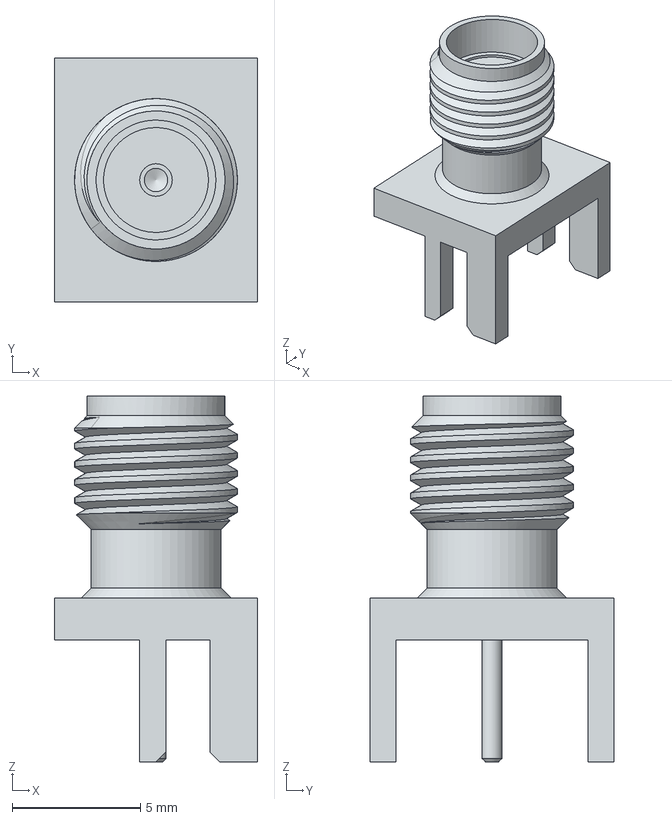
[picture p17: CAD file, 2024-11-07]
hw/FBS_kicad_lib/3d_models/200_coaxial_connector/SMA_142-0701-801_EdgeMount.step
7.92 x 9.53 x 14.3 mm

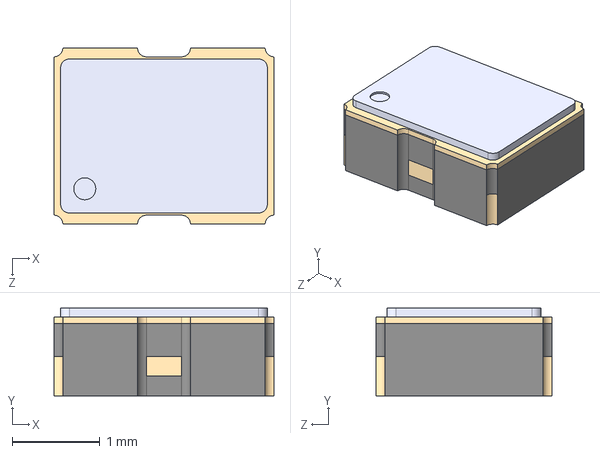
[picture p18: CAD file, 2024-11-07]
hw/FBS_kicad_lib/3d_models/20_oscillator/ECS-TXO-25CSMV.step
2.50 x 1.00 x 2.00 mm

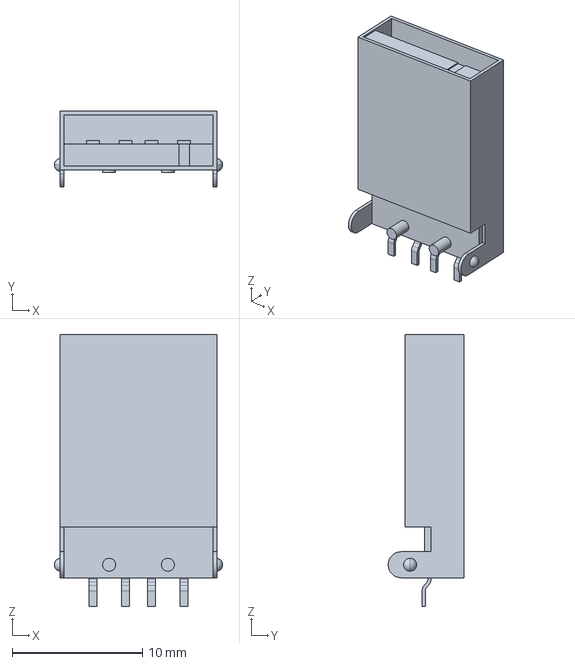
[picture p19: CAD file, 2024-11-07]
hw/FBS_kicad_lib/3d_models/210_USB_connector/USB_male_typeA_2.0_1-1734028-1.stp
12.9 x 5.80 x 20.9 mm

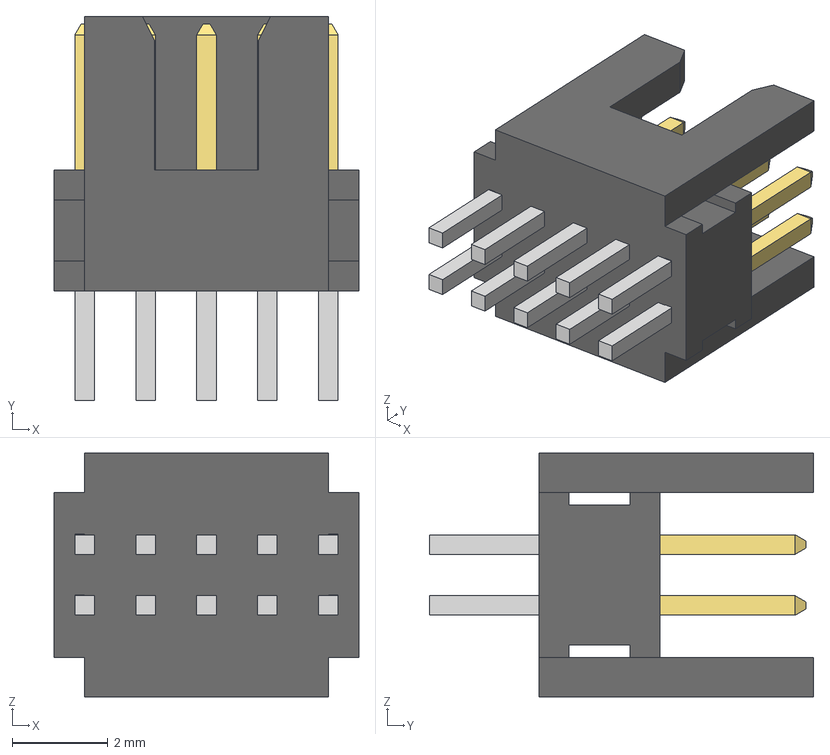
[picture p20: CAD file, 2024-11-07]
hw/FBS_kicad_lib/3d_models/220_cortex-M_debug_connector/FTSH-105-01-F-D-K.step
6.35 x 8.00 x 5.08 mm
FTSH-105-01-F-D-K_body
FTSH-105-01-F-D-K_pins1
FTSH-105-01-F-D-K_pins2

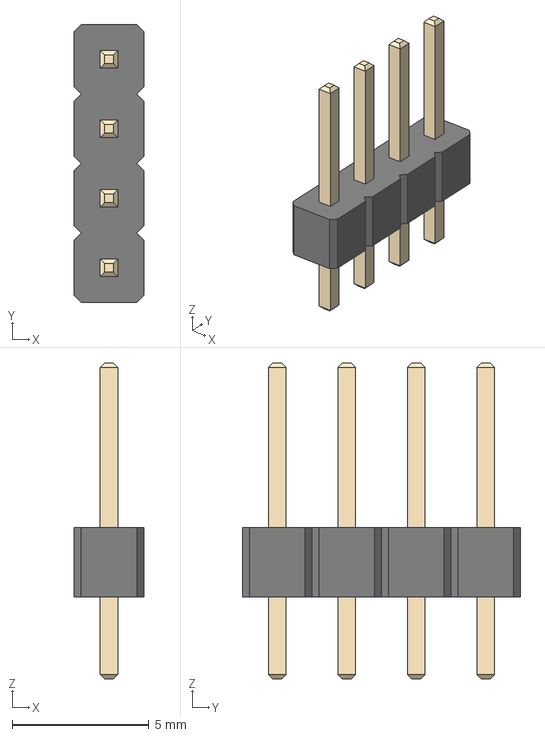
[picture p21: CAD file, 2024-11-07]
hw/FBS_kicad_lib/3d_models/300_pin_header_connector/PinHeader_1x04_P2.54mm_Vertical.step
2.54 x 10.2 x 11.5 mm

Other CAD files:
hw/FBS_kicad_lib/3d_models/2_inductor_SMD/L_0603_1608Metric.step
hw/FBS_kicad_lib/3d_models/3_LED_SMD/LED_0402_1005Metric.step
hw/FBS_kicad_lib/3d_models/4_diode_SMD/D_0402_1005Metric.STEP
hw/FBS_kicad_lib/3d_models/50_RF_filter/DLFCV-1000+.stp
hw/FBS_kicad_lib/3d_models/105_SOT_package/SOT-23-3.step
hw/FBS_kicad_lib/3d_models/105_SOT_package/SOT-23-5.step
hw/FBS_kicad_lib/3d_models/105_SOT_package/SOT-363.step
hw/FBS_kicad_lib/3d_models/1_capacitor_SMD/C_0402_1005Metric.step
hw/FBS_kicad_lib/3d_models/1_capacitor_SMD/C_1206_3216Metric.step
hw/FBS_kicad_lib/3d_models/220_cortex-M_debug_connector/FTSH-105-01-F-DV-K.step
hw/FBS_kicad_lib/3d_models/2_inductor_SMD/L_0402_1005Metric.step
hw/FBS_kicad_lib/3d_models/2_inductor_SMD/L_0805_2012Metric.step
hw/FBS_kicad_lib/3d_models/300_pin_header_connector/PinHeader_1x02_P2.54mm_Vertical.step
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

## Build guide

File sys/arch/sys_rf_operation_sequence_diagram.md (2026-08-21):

# sys_rf_operation_sequence_diagram

## Description

Dynamic view of a representative RF-operation exchange. The sequence traces the User request through `sysc_hostCli` and `sysi_usbExternal`, `sysc_controller` processing, and the mutually exclusive TX/RX interaction through `sysi_rfExternal`. TX has no operation response; RX returns its result or response to the User through `sysi_usbExternal` and the User CLI.

## Diagram

```mermaid
sequenceDiagram
    actor User
    participant SYS_ARCH_COMPONENT_2 as sysc_hostCli
    participant SYS_ARCH_COMPONENT_1 as sysc_controller
    participant RFENV as RF environment

    User->>SYS_ARCH_COMPONENT_2: RF operation request
    %% SYS_ARCH_INTERFACE_1
    SYS_ARCH_COMPONENT_2->>SYS_ARCH_COMPONENT_1: sysi_usbExternal - RF operation request
    SYS_ARCH_COMPONENT_1->>SYS_ARCH_COMPONENT_1: Process request
    alt TX
        %% SYS_ARCH_INTERFACE_2
        SYS_ARCH_COMPONENT_1->>RFENV: sysi_rfExternal - TX
    else RX
        %% SYS_ARCH_INTERFACE_2
        RFENV->>SYS_ARCH_COMPONENT_1: sysi_rfExternal - RX
        %% SYS_ARCH_INTERFACE_1
        SYS_ARCH_COMPONENT_1-->>SYS_ARCH_COMPONENT_2: sysi_usbExternal - RX response
        SYS_ARCH_COMPONENT_2-->>User: RX response
    end
```

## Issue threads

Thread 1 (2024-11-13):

Lower than expected peak-to-peak signal on OSC_IN input pin

FBS93, 2024-11-13:
Using an oscilloscope to check the OSC_IN input pin, I observed a 130mV peak-to-peak signal. However, according to the specifications, the signal for this pin shall be within the range of 0.4 to 1.2 Vpeak-to-peak.

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

Currently, no functional issues have been detected related to this issue; the RF dongle is operating as expected. However, this is an area for potential improvement in future versions.

Focus points for troubleshooting:
- Verify if the TCXO provides the expected output as per manufacturer specifications, with no output load.
- If the output signal does not meet specifications, consider replacing the oscillator with an alternative."

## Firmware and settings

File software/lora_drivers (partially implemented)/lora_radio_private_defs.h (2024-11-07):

#ifndef SUBGHZ_REGISTERS_H_
#define SUBGHZ_REGISTERS_H_

/**
 * @brief  Sub-GHz radio RAM definition
 * @note   The sub-GHz radio peripheral RAM address can be accessed by sub-GHz radio command
 *         SUBGRF_WriteRegisters() and SUBGRF_ReadRegisters() "
 * @note   These RAM addresses are used to control accurately ramp-up, ramp-down and length of a frame
 */
/*Sub-GHz radio ramp-up High register*/
#define SUBGHZ_RAM_RAMPUPH ((uint16_t)0x00F0)
/*Sub-GHz radio ramp-up Low register*/
#define SUBGHZ_RAM_RAMPUPL ((uint16_t)0x00F1)
/*Sub-GHz radio ramp-down High register*/
#define SUBGHZ_RAM_RAMPDNH ((uint16_t)0x00F2)
/*Sub-GHz radio ramp-down Low register*/
#define SUBGHZ_RAM_RAMPDNL ((uint16_t)0x00F3)
/*Sub-GHz radio frame limit High register*/
#define SUBGHZ_RAM_FRAMELIMH ((uint16_t)0x00F4)
/*Sub-GHz radio frame limit Low register*/
#define SUBGHZ_RAM_FRAMELIML ((uint16_t)0x00F5)

/**
 * @brief  Sub-GHz radio register definition
 * @note   The sub-GHz radio peripheral registers can be accessed by sub-GHz radio command
 *         SUBGRF_WriteRegisters() and SUBGRF_ReadRegisters() "
 */
/*Sub-GHz radio generic bit synchronization register*/
#define SUBGHZ_GBSYNCR ((uint16_t)0x06AC)
/*Sub-GHz radio generic CFO High register */
#define SUBGHZ_GCFORH ((uint16_t)0x06B0)
/*Sub-GHz radio generic CFO Low register */
#define SUBGHZ_GCFORL ((uint16_t)0x06B1)
/*Sub-GHz radio generic pktCtl1 register*/
#define SUBGHZ_GPKTCTL1R ((uint16_t)0x06B4)
/*Sub-GHz radio generic packet control 1A register*/
#define SUBGHZ_GPKTCTL1AR ((uint16_t)0x06B8)
/*Sub-GHz radio generic whitening LSB register*/
#define SUBGHZ_GWHITEINIRL ((uint16_t)0x06B9)
/*Sub-GHz radio generic rtx register*/
#define SUBGHZ_GRTXPLDLEN ((uint16_t)0x06BB)
/*Sub-GHz radio generic CRC initial High register*/
#define SUBGHZ_GCRCINIRH ((uint16_t)0x06BC)
/*Sub-GHz radio generic CRC initial Low register*/
#define SUBGHZ_GCRCINIRL ((uint16_t)0x06BD)
/*Sub-GHz radio generic CRC polynomial High register*/
#define SUBGHZ_GCRCPOLRH ((uint16_t)0x06BE)
/*Sub-GHz radio generic CRC polynomial Low register*/
#define SUBGHZ_GCRCPOLRL ((uint16_t)0x06BF)
/*Sub-GHz radio generic synchronization word control register 0*/
#define SUBGHZ_GSYNCR0 ((uint16_t)0x06C0)
/*Sub-GHz radio generic synchronization word control register 1*/
#define SUBGHZ_GSYNCR1 ((uint16_t)0x06C1)
/*Sub-GHz radio generic synchronization word control register 2*/
#define SUBGHZ_GSYNCR2 ((uint16_t)0x06C2)
/*Sub-GHz radio generic synchronization word control register 3*/
#define SUBGHZ_GSYNCR3 ((uint16_t)0x06C3)
/*Sub-GHz radio generic synchronization word control register 4*/
#define SUBGHZ_GSYNCR4 ((uint16_t)0x06C4)
/*Sub-GHz radio generic synchronization word control register 5*/
#define SUBGHZ_GSYNCR5 ((uint16_t)0x06C5)
/*Sub-GHz radio generic synchronization word control register 6*/
#define SUBGHZ_GSYNCR6 ((uint16_t)0x06C6)
/*Sub-GHz radio generic synchronization word control register 7*/
#define SUBGHZ_GSYNCR7 ((uint16_t)0x06C7)
/*Sub-GHz radio generic node address register*/
#define SUBGHZ_GNODEADDR ((uint16_t)0x06CD)
/*Sub-GHz radio generic broadacst address register*/
#define SUBGHZ_GBCASTADDR ((uint16_t)0x06CE)
/*Sub-GHz radio generic Afc register*/
#define SUBGHZ_GAFCR ((uint16_t)0x06D1)
/*Sub-GHz radio Lora Payload Length */
#define SUBGHZ_LPLDLENR ((uint16_t)0x0702)
/*Sub-GHz radio Lora synchro timeout */
#define SUBGHZ_LSYNCTIMEOUTR ((uint16_t)0x0706)
/*Sub-GHz radio Lora IQ polarity High register*/
#define SUBGHZ_LIQPOLRH ((uint16_t)0x0735)
/*Sub-GHz radio Lora IQ polarity Low register*/
#define SUBGHZ_LIQPOLRL ((uint16_t)0x0736)
/*Sub-GHz radio LoRa synchronization word High register*/
#define SUBGHZ_LSYNCRH ((uint16_t)0x0740)
/*Sub-GHz radio LoRa synchronization word Low register*/
#define SUBGHZ_LSYNCRL ((uint16_t)0x0741)
/*Sub-GHz radio txAddrPtr register*/
#define SUBGHZ_TXADRPTR ((uint16_t)0x0802)
/*Sub-GHz radio rxAddrPtr register*/
#define SUBGHZ_RXADRPTR ((uint16_t)0x0803)
/*Sub-GHz radio Rx Bandwidth selector register */
#define SUBGHZ_BWSELR ((uint16_t)0x0807)
/*Sub-GHz radio random number register 3*/
#define SUBGHZ_RNGR3 ((uint16_t)0x0819)
/*Sub-GHz radio  random number register 2*/
#define SUBGHZ_RNGR2 ((uint16_t)0x081A)
/*Sub-GHz radio  random number register 1*/
#define SUBGHZ_RNGR1 ((uint16_t)0x081B)
/*Sub-GHz radio  random number register 0*/
#define SUBGHZ_RNGR0 ((uint16_t)0x081C)
/*Sub-GHz radio SD resolution*/
#define SUBGHZ_SDCFG0R ((uint16_t)0x0889)
/*Sub-GHz radio Agc Gfo Reset Rssi Control register*/
#define SUBGHZ_AGCRSSICTL0R ((uint16_t)0x089B)
/*Sub-GHz radio receiver gain control register*/
#define SUBGHZ_RXGAINCR ((uint16_t)0x08AC)
/*Sub-GHz radio Agc Gfo Reset Config register*/
#define SUBGHZ_AGCGFORSTCFGR ((uint16_t)0x08B8)
/*Sub-GHz radio Agc Gfo Reset Power Threshold register*/
#define SUBGHZ_AGCGFORSTPOWTHR ((uint16_t)0x08B9)
/*Sub-GHz radio Tx clamp register*/
#define SUBGHZ_TXCLAMPR ((uint16_t)0x08D8)
/*Sub-GHz radio disable LNA register*/
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

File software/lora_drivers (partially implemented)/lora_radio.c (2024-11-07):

#include <stdint.h>

#include "stm32wlxx_hal.h"

#include "lora_radio.h"
#include "lora_radio_private_defs.h"
#include "rf_switch.h"

/* Lora info:
 *
 * https://blog.classycode.com/lora-sync-word-compatibility-between-sx127x-and-sx126x-460324d1787a
 *
 */

/* ST info
 *
 * https://www.st.com/resource/en/reference_manual/rm0453-stm32wl5x-advanced-armbased-32bit-mcus-with-subghz-radio-solution-stmicroelectronics.pdf
 * https://www.st.com/resource/en/datasheet/stm32wle5c8.pdf
 * https://www.st.com/resource/en/errata_sheet/es0500-stm32wl55xx-stm32wl54xx-device-errata-stmicroelectronics.pdf
 * https://www.st.com/resource/en/user_manual/um2592-stm32wl-nucleo64-board-mb1389-stmicroelectronics.pdf
 *
 */

/* SemTech info
 *
 * DS_SX1261-2_V2_1.pdf
 *
 */

/*!
 * \brief TODO
 */
typedef struct
{
	loraRadio_spreadingFactors_t spreading_factor;
	loraRadio_bandwidths_t bandwidth;
	loraRadio_codingRates_t coding_rate;
	loraRadio_lowDataRateOptimization_t low_data_rate_opt;
	uint32_t channel_freq;
} loraRadio_modulationParameters_t;

/*!
 * \brief TODO
 */
typedef struct
{
	loraRadio_packetTypes_t packet_type;
	uint16_t preamble_len;
	loraRadio_headerType_t header_type;
	loraRadio_crcModes_t crc_mode;
	loraRadio_iqModes_t iq_mode;
} loraRadio_packetParameters_t;

/*!
 * \brief TODO
 */
typedef struct
{
	loraRadio_modulationParameters_t modulation_parameters;
	loraRadio_packetParameters_t packet_parameters;
	int8_t tx_power_dBm;
	loraRadio_txModes_t tx_mode;
	uint32_t tx_timeout;
} loraRadio_txParameters_t;

/*!
 * \brief TODO
 */
typedef struct
{
	loraRadio_modulationParameters_t modulation_parameters;
	loraRadio_packetParameters_t packet_parameters;
	uint8_t symbol_timeout; // TODO: Document --> used to configure the number of LoRa symbols to be received before starting the reception of a LoRa packet
	loraRadio_rxModes_t rx_mode;
	loraRadio_rxPowerMode_t rx_power_mode;
	uint32_t rx_timeout;
	uint32_t listening_mode_rx_time;
	uint32_t listening_mode_sleep_time;
	uint32_t rx_duty_cycle_preamble_detect_timeout; /*TODO: document --> See STM32WL Errata: RadioSetRxDutyCycle*/
} loraRadio_rxParameters_t;

/* External variables --------------------------------------------------------*/
// TODO:Try tyo avoid global variables in STM32CubeMX code generation
extern SUBGHZ_HandleTypeDef hsubghz; // handler generated by st api drivers
// static variables
static loraRadio_events_t loraRadio_events;
static loraRadio_txParameters_t loraRadio_txParameters;
static loraRadio_rxParameters_t loraRadio_rxParameters;

// HAL_SUBGHz Callbacks re-definitions. override the default callback of stm32wlxx_hal_subghz.c

/**
 * @brief  Packet transmission completed callback.
 * @param  hsubghz pointer to a SUBGHZ_HandleTypeDef structure that contains
 *                 the configuration information for SUBGHZ module.
 * @retval None
 */
void __attribute__((weak)) HAL_SUBGHZ_TxCpltCallback(SUBGHZ_HandleTypeDef *hsubghz)
{
	/* Prevent unused argument(s) compilation warning */
	(void)hsubghz;
}

/**
 * @brief  Packet received callback.
 * @param  hsubghz pointer to a SUBGHZ_HandleTypeDef structure that contains
 *                 the configuration information for SUBGHZ module.
 * @retval None
 */
void __attribute__((weak)) HAL_SUBGHZ_RxCpltCallback(SUBGHZ_HandleTypeDef *hsubghz)
{
	/* Prevent unused argument(s) compilation warning */
	(void)hsubghz;
}

/**
 * @brief  Preamble Detected callback.
 * @param  hsubghz pointer to a SUBGHZ_HandleTypeDef structure that contains
 *                 the configuration information for SUBGHZ module.
 * @retval None
 */
void __attribute__((weak)) HAL_SUBGHZ_PreambleDetectedCallback(SUBGHZ_HandleTypeDef *hsubghz)
{
	/* Prevent unused argument(s) compilation warning */
	(void)hsubghz;

	// Manage the following
	/*See STM32WL Errata: RadioSetRxDutyCycle*/
}

/**
 * @brief  Valid sync word detected callback.
 * @param  hsubghz pointer to a SUBGHZ_HandleTypeDef structure that contains
 *                 the configuration information for SUBGHZ module.
 * @retval None
 */
void __attribute__((weak)) HAL_SUBGHZ_SyncWordValidCallback(SUBGHZ_HandleTypeDef *hsubghz)
{
	/* Prevent unused argument(s) compilation warning */
	(void)hsubghz;
}

/**
 * @brief  Valid LoRa header received callback.
 * @param  hsubghz pointer to a SUBGHZ_HandleTypeDef structure that contains
 *                 the configuration information for SUBGHZ module.
 * @retval None
 */
void __attribute__((weak)) HAL_SUBGHZ_HeaderValidCallback(SUBGHZ_HandleTypeDef *hsubghz)
{
	/* Prevent unused argument(s) compilation warning */
	(void)hsubghz;
}

/**
 * @brief  LoRa header CRC error callback.
 * @param  hsubghz pointer to a SUBGHZ_HandleTypeDef structure that contains
 *                 the configuration information for SUBGHZ module.
 * @retval None
 */
void __attribute__((weak)) HAL_SUBGHZ_HeaderErrorCallback(SUBGHZ_HandleTypeDef *hsubghz)
{
	/* Prevent unused argument(s) compilation warning */
	(void)hsubghz;
}

/**
 * @brief  Wrong CRC received callback.
 * @param  hsubghz pointer to a SUBGHZ_HandleTypeDef structure that contains
 *                 the configuration information for SUBGHZ module.
 * @retval None
 */
void __attribute__((weak)) HAL_SUBGHZ_CRCErrorCallback(SUBGHZ_HandleTypeDef *hsubghz)
{
	/* Prevent unused argument(s) compilation warning */
	(void)hsubghz;
}

/**
 * @brief  Channel activity detection status callback.
 * @note   Unified callback for CAD Done and CAD activity interrupts.
 * @param  hsubghz pointer to a SUBGHZ_HandleTypeDef structure that contains
 *                 the configuration information for SUBGHZ module.
 * @param  cadstatus reports whether activity is detected or not
 * @retval None
 */
void __attribute__((weak)) HAL_SUBGHZ_CADStatusCallback(SUBGHZ_HandleTypeDef *hsubghz,
																												HAL_SUBGHZ_CadStatusTypeDef cadstatus)
{
	/* Prevent unused argument(s) compilation warning */
	(void)hsubghz;
	(void)cadstatus;
}

/**
 * @brief  Rx or Tx Timeout callback.
 * @param  hsubghz pointer to a SUBGHZ_HandleTypeDef structure that contains
 *                 the configuration information for SUBGHZ module.
 * @retval None
 */
void __attribute__((weak)) HAL_SUBGHZ_RxTxTimeoutCallback(SUBGHZ_HandleTypeDef *hsubghz)
{
	/* Prevent unused argument(s) compilation warning */
	(void)hsubghz;
}

/**
 * @brief  LR FHSS Hop callback.
 * @param  hsubghz pointer to a SUBGHZ_HandleTypeDef structure that contains
 *                 the configuration information for SUBGHZ module.
 * @retval None
 */
void __attribute__((weak)) HAL_SUBGHZ_LrFhssHopCallback(SUBGHZ_HandleTypeDef *hsubghz)
{
	/* Prevent unused argument(s) compilation warning */
	(void)hsubghz;
}

// TODO: Remove all weak attributes in callbacks

/*!
 * \brief TODO
 */
static void loraRadio_writeRegister(uint16_t address, uint8_t value)
{
	SUBGHZ_CRITICAL_SECTION_BEGIN();
	HAL_SUBGHZ_WriteRegisters(&hsubghz, address, &value, 1);
	SUBGHZ_CRITICAL_SECTION_END();
}
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

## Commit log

2024-11-07 Add all project files for the first public release
    [0ZCM0020FF2G.stp, C_0402_1005Metric.step, C_0603_1608Metric.step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]
2026-08-02 Reorganize project directories
    [0ZCM0020FF2G.stp, C_0402_1005Metric.step, C_0603_1608Metric.step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]
2026-08-02 Add KiCad runtime state and basic configuration
2026-08-02 Ignore KiCad local history
2026-08-03 Adapt KiCad stackup and DRC rules for PCBWay
    [STM32WLE5_RF_dongle.kicad_pcb]
2026-08-04 Refactor routing for PCBWay manufacturing
    [MCU.kicad_sch, RF_front_end.kicad_sch, STM32WLE5_RF_dongle.kicad_pcb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]
2026-08-06 Generate PCBWay fabrication and assembly outputs
    [MCU.kicad_sch, RF_front_end.kicad_sch, STM32WLE5_RF_dongle.kicad_pcb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]
2026-08-06 Align minimum drill rule with via design
2026-08-07 Update layer export selection
    [STM32WLE5_RF_dongle.kicad_pcb]
2026-08-14 Update PCB tracing according to PCBWay engineering team stackup definition and feedback
    [STM32WLE5_RF_dongle.kicad_pcb]
2026-08-15 Update PCB text box documentation
    [STM32WLE5_RF_dongle.kicad_pcb]
2026-08-19 Fix RF switch VCTL control divider and manufacturing outputs
    [MCU.kicad_sch, RF_front_end.kicad_sch, STM32WLE5_RF_dongle.kicad_pcb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]
2026-08-20 Update KiCad state after adding a new footprint library
2026-09-03 Clarify FB1 and J8 component metadata
    [MCU.kicad_sch, USB_interface_and_power.kicad_sch]
2026-10-13 Correct startup, SPI synchronization and duty-cycle handling

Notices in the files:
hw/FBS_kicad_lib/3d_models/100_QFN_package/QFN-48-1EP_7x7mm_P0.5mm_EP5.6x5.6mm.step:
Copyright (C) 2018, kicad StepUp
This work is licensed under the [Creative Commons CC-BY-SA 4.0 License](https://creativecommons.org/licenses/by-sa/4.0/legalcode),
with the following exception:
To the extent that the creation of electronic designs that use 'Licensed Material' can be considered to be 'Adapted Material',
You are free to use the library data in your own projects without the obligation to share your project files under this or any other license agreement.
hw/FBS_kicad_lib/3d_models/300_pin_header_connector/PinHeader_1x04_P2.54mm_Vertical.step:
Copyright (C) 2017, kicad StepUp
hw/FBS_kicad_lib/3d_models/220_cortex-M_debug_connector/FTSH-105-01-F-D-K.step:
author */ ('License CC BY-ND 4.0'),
